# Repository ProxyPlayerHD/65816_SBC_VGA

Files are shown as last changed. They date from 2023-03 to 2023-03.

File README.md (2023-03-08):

# 65816 VGA Card
This is a simple VGA Expansion card designed for my 65816 SBC<br>
It uses an `ATF1508AS` CPLD for all the Logic, and 4x `IDT7005S` or `IDT7006S` Dual Port SRAM ICs for a total of either 32kB or 64kB of VRAM. (or something inbetween)

the Logic uploaded here is for 32kB of VRAM, 640x400 Monochrome (1 bit per pixel or "bpp") with an Interrupt every time a frame finished drawing.<br>
Though once i get my hands on some 16kB Chips i'll likely do a few more versions of the Logic and also upload them here.

# Folders
* "Downloaded Libs" contains the symbols and footprints for the KiCad Project
* "Logic" contains the... well Logic for the entire thing. i've included the original .dig file (requires [Digital](https://github.com/hneemann/Digital) to open), and already generated .v (Verilog) and .pof/.jed (program files in case you want to skip setting up Quartus to generate them yourself)
* "Gerbers" contains all required Gerbers to order yourself the PCB

# Misc

regards to the Logic:
the `CA13` line (CPU Address bit 13) is only required when dealing with 8kB DP-SRAM Chips,<br>
and the `VA13` (Video Address bit 13) line is only required when dealing with 16kB DP-SRAM Chips.<br>
also right now the decoding logic puts the VRAM on the CPU side at address `$FF8000`

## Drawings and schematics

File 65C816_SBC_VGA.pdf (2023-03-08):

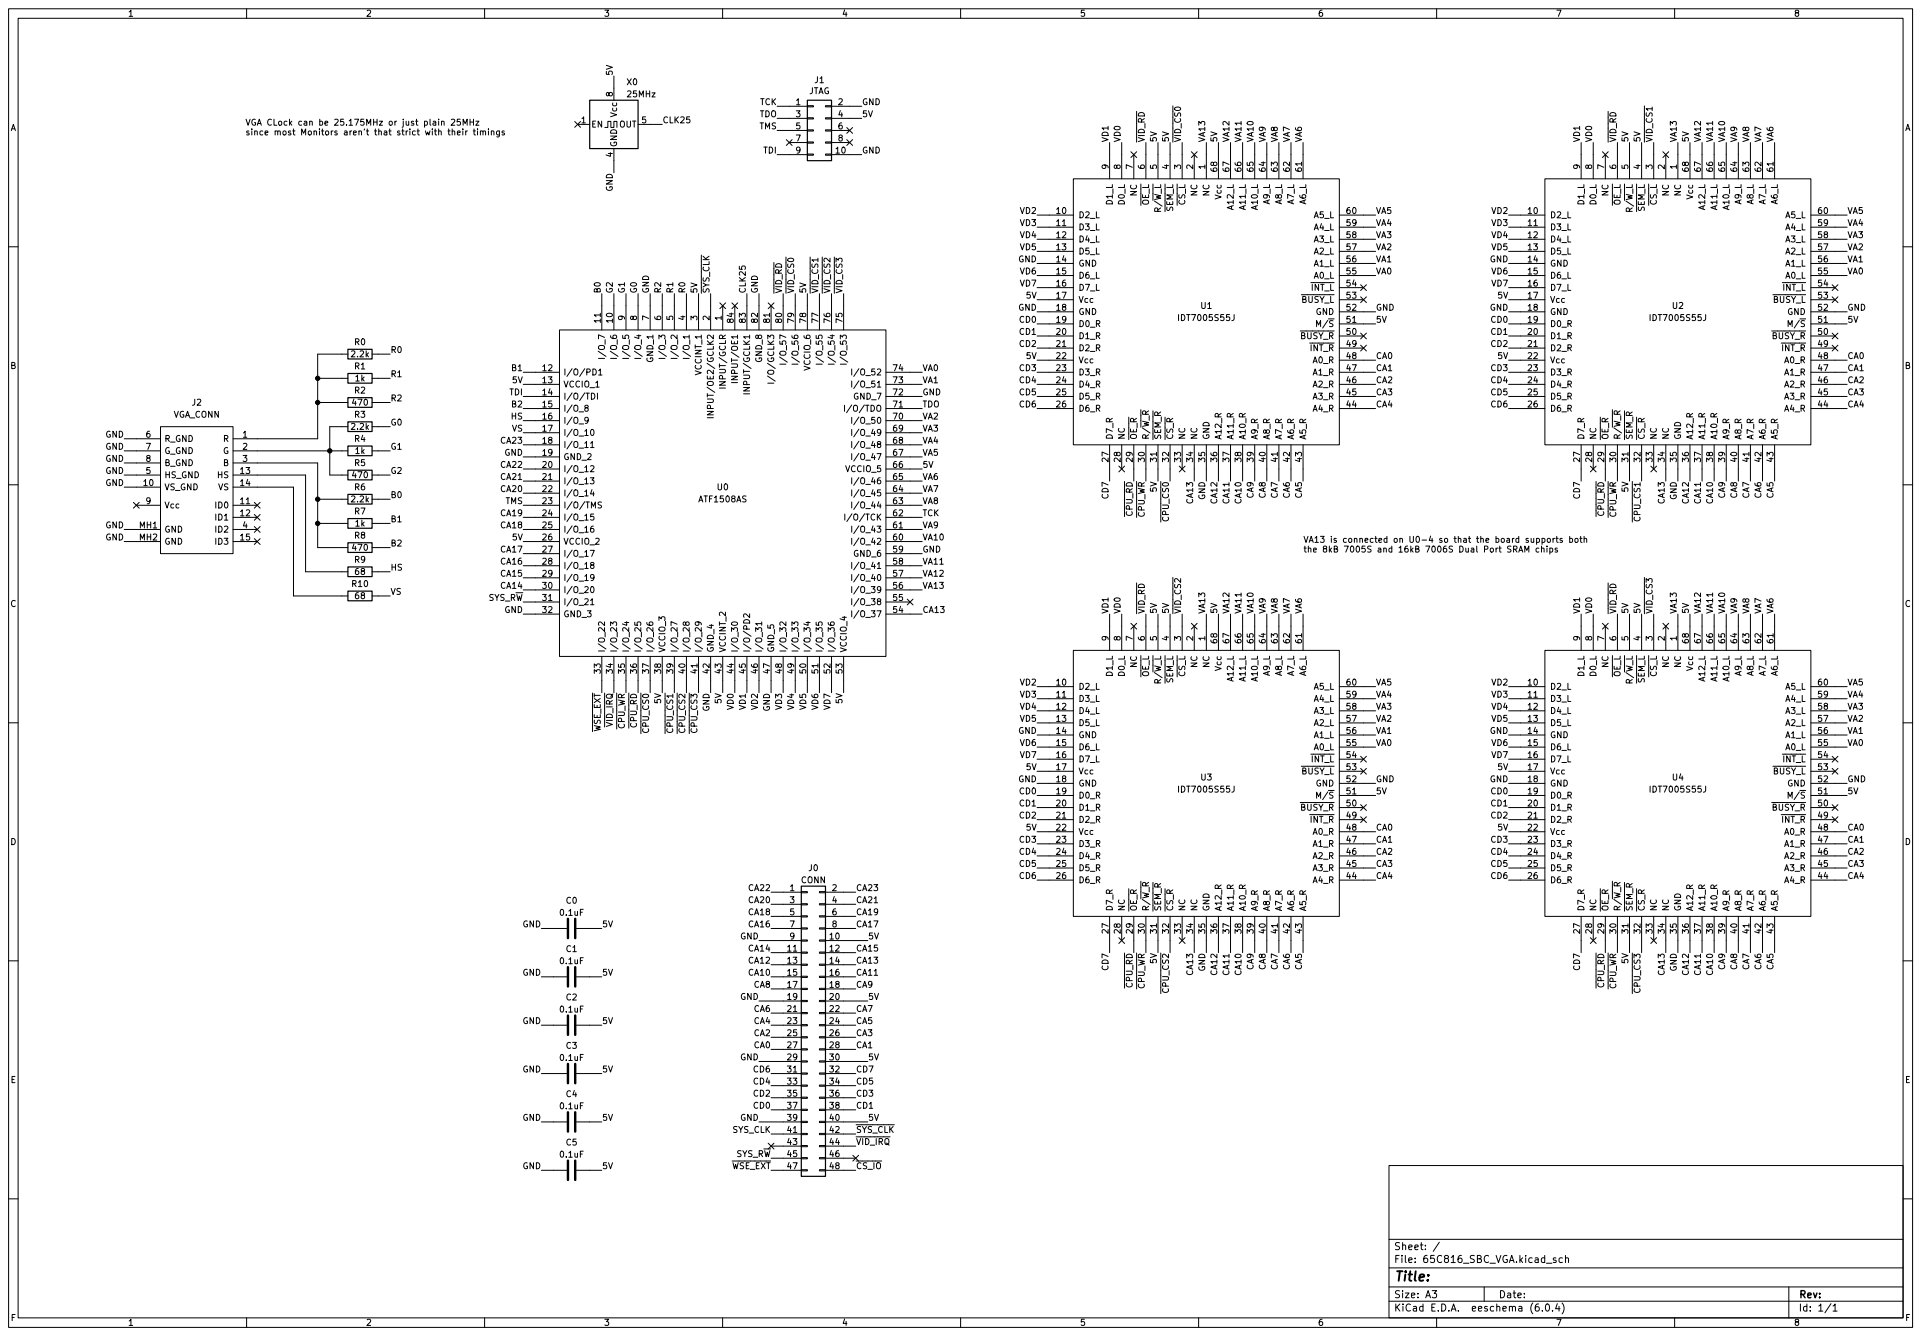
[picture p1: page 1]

VGA CLock can be 25.175MHz or just plain 25MHz
since most Monitors aren't that strict with their timings

2 D1_R 20 D2_R 21 Vcc 22 D3_R 23 D4_R 24 D5_R 25 D6_R 26 D7_R 27 NC 28 ~{OE_R} 29 ~{CS_L} 3 R/~{W_R} 30 ~{SEM_R} 31 ~{CS_R} 32 NC 33 NC 34 GND 35 A12_R 36 A11_R 37 A10_R 38 A9_R 39 ~{SEM_L} 4 A8_R 40 A7_R 41 A6_R 42 A5_R 43 A4_R 44 A3_R 45 A2_R 46 A1_R 47 A0_R 48 ~{INT_R} 49 R/~{W_L} 5 ~{BUSY_R} 50 M/~{S} 51 GND 52 ~{BUSY_L} 53 ~{INT_L} 54 A0_L 55 A1_L 56 A2_L 57 A3_L 58 A4_L 59 ~{OE_L} 6 A5_L 60 A6_L 61 A7_L 62 A8_L 63 A9_L 64 A10_L 65 A11_L 66 A12_L 67 Vcc 68 NC

1 D2_L 10 D3_L 11 D4_L 12 D5_L 13 GND 14 D6_L 15 D7_L 16 Vcc 17 GND 18 D0_R 19 NC

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

VA13 is connected on U0-4 so that the board supports both
the 8kB 7005S and 16kB 7006S Dual Port SRAM chips

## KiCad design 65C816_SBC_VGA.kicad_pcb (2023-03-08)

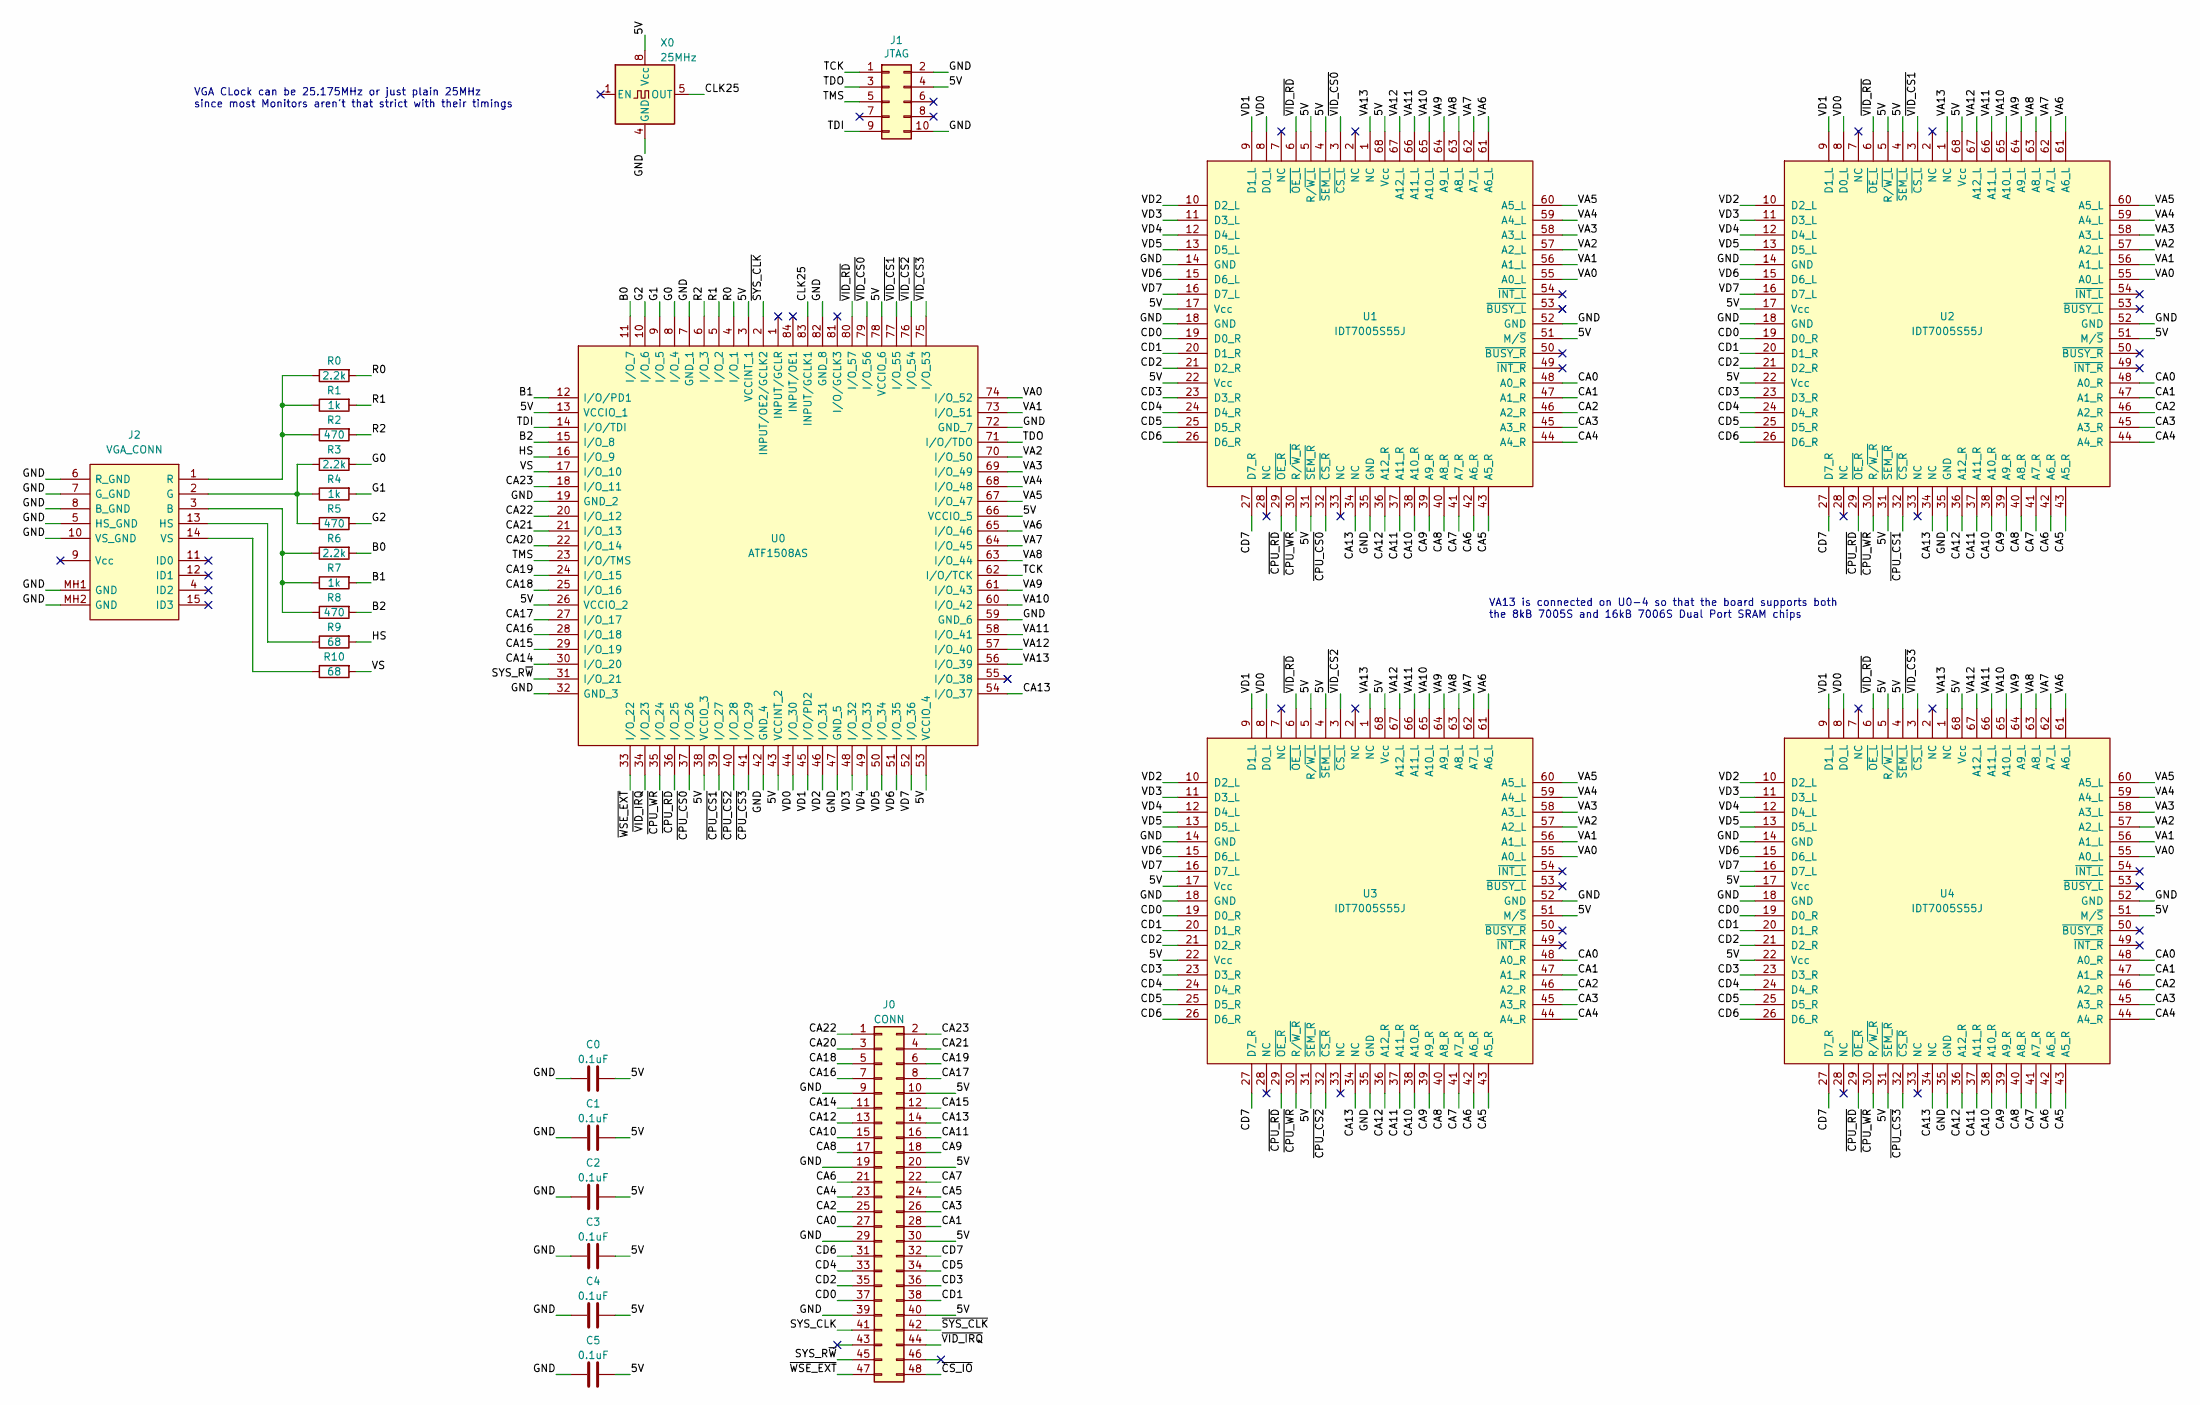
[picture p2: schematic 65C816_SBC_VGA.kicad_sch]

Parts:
C0, C1, C2, C3, C4, C5: 0.1uF; C_Disc_D4.3mm_W1.9mm_P5.00mm
J0: CONN; CARD_EDGE
J1: JTAG; PinHeader_2x05_P2.54mm_Vertical
J2: VGA_CONN; Mouser Part Number 156-3315-E
R0, R3, R6: 2.2k; R_Axial_DIN0207_L6.3mm_D2.5mm_P2.54mm_Vertical
R1, R4, R7: 1k; R_Axial_DIN0207_L6.3mm_D2.5mm_P2.54mm_Vertical
R2, R5, R8: 470; R_Axial_DIN0207_L6.3mm_D2.5mm_P2.54mm_Vertical
R9, R10: 68; R_Axial_DIN0207_L6.3mm_D2.5mm_P2.54mm_Vertical
U0: ATF1508AS; PLCC-84_THT-Socket
U1, U2, U3, U4: IDT7005S55J; PLCC-68_THT-Socket
X0: 25MHz; Oscillator_DIP-8

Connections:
/5V: C0.2, C1.2, C2.2, C3.2, C4.2, C5.2, J0.10, J0.20, J0.30, J0.40, J1.4, U0.3 (VCCINT_1), U0.13 (VCCIO_1), U0.26 (VCCIO_2), U0.38 (VCCIO_3), U0.43 (VCCINT_2), U0.53 (VCCIO_4), U0.66 (VCCIO_5), U0.78 (VCCIO_6), U1.4 (~SEM_L), U1.5 (R/~W_L), U1.17 (Vcc), U1.22 (Vcc), U1.31 (~SEM_R), U1.51 (M/~S), U1.68 (Vcc), U2.4 (~SEM_L), U2.5 (R/~W_L), U2.17 (Vcc), U2.22 (Vcc), U2.31 (~SEM_R), U2.51 (M/~S), U2.68 (Vcc), U3.4 (~SEM_L), U3.5 (R/~W_L), U3.17 (Vcc), U3.22 (Vcc), U3.31 (~SEM_R), U3.51 (M/~S), U3.68 (Vcc), U4.4 (~SEM_L), U4.5 (R/~W_L), U4.17 (Vcc), U4.22 (Vcc), U4.31 (~SEM_R), U4.51 (M/~S), U4.68 (Vcc), X0.8 (Vcc)
/B0: R6.2, U0.11 (I/O_7)
/B1: R7.2, U0.12 (I/O/PD1)
/B2: R8.2, U0.15 (I/O_8)
/CA0: J0.27, U1.48 (A0_R), U2.48 (A0_R), U3.48 (A0_R), U4.48 (A0_R)
/CA1: J0.28, U1.47 (A1_R), U2.47 (A1_R), U3.47 (A1_R), U4.47 (A1_R)
/CA2: J0.25, U1.46 (A2_R), U2.46 (A2_R), U3.46 (A2_R), U4.46 (A2_R)
/CA3: J0.26, U1.45 (A3_R), U2.45 (A3_R), U3.45 (A3_R), U4.45 (A3_R)
/CA4: J0.23, U1.44 (A4_R), U2.44 (A4_R), U3.44 (A4_R), U4.44 (A4_R)
/CA5: J0.24, U1.43 (A5_R), U2.43 (A5_R), U3.43 (A5_R), U4.43 (A5_R)
/CA6: J0.21, U1.42 (A6_R), U2.42 (A6_R), U3.42 (A6_R), U4.42 (A6_R)
/CA7: J0.22, U1.41 (A7_R), U2.41 (A7_R), U3.41 (A7_R), U4.41 (A7_R)
/CA8: J0.17, U1.40 (A8_R), U2.40 (A8_R), U3.40 (A8_R), U4.40 (A8_R)
/CA9: J0.18, U1.39 (A9_R), U2.39 (A9_R), U3.39 (A9_R), U4.39 (A9_R)
/CA10: J0.15, U1.38 (A10_R), U2.38 (A10_R), U3.38 (A10_R), U4.38 (A10_R)
/CA11: J0.16, U1.37 (A11_R), U2.37 (A11_R), U3.37 (A11_R), U4.37 (A11_R)
/CA12: J0.13, U1.36 (A12_R), U2.36 (A12_R), U3.36 (A12_R), U4.36 (A12_R)
/CA13: J0.14, U0.54 (I/O_37), U1.34 (NC), U2.34 (NC), U3.34 (NC), U4.34 (NC)
/CA14: J0.11, U0.30 (I/O_20)
/CA15: J0.12, U0.29 (I/O_19)
/CA16: J0.7, U0.28 (I/O_18)
/CA17: J0.8, U0.27 (I/O_17)
/CA18: J0.5, U0.25 (I/O_16)
/CA19: J0.6, U0.24 (I/O_15)
/CA20: J0.3, U0.22 (I/O_14)
/CA21: J0.4, U0.21 (I/O_13)
/CA22: J0.1, U0.20 (I/O_12)
/CA23: J0.2, U0.18 (I/O_11)
/CD0: J0.37, U1.19 (D0_R), U2.19 (D0_R), U3.19 (D0_R), U4.19 (D0_R)
/CD1: J0.38, U1.20 (D1_R), U2.20 (D1_R), U3.20 (D1_R), U4.20 (D1_R)
/CD2: J0.35, U1.21 (D2_R), U2.21 (D2_R), U3.21 (D2_R), U4.21 (D2_R)
/CD3: J0.36, U1.23 (D3_R), U2.23 (D3_R), U3.23 (D3_R), U4.23 (D3_R)
/CD4: J0.33, U1.24 (D4_R), U2.24 (D4_R), U3.24 (D4_R), U4.24 (D4_R)
/CD5: J0.34, U1.25 (D5_R), U2.25 (D5_R), U3.25 (D5_R), U4.25 (D5_R)
/CD6: J0.31, U1.26 (D6_R), U2.26 (D6_R), U3.26 (D6_R), U4.26 (D6_R)
/CD7: J0.32, U1.27 (D7_R), U2.27 (D7_R), U3.27 (D7_R), U4.27 (D7_R)
/CLK25: U0.83 (INPUT/GCLK1), X0.5 (OUT)
/G0: R3.2, U0.8 (I/O_4)
/G1: R4.2, U0.9 (I/O_5)
/G2: R5.2, U0.10 (I/O_6)
/GND: C0.1, C1.1, C2.1, C3.1, C4.1, C5.1, J0.9, J0.19, J0.29, J0.39, J1.2, J1.10, J2.5 (HS_GND), J2.6 (R_GND), J2.7 (G_GND), J2.8 (B_GND), J2.10 (VS_GND), J2.MH1 (GND), J2.MH2 (GND), U0.7 (GND_1), U0.19 (GND_2), U0.32 (GND_3), U0.42 (GND_4), U0.47 (GND_5), U0.59 (GND_6), U0.72 (GND_7), U0.82 (GND_8), U1.14 (GND), U1.18 (GND), U1.35 (GND), U1.52 (GND), U2.14 (GND), U2.18 (GND), U2.35 (GND), U2.52 (GND), U3.14 (GND), U3.18 (GND), U3.35 (GND), U3.52 (GND), U4.14 (GND), U4.18 (GND), U4.35 (GND), U4.52 (GND), X0.4 (GND)
/HS: R9.2, U0.16 (I/O_9)
/R0: R0.2, U0.4 (I/O_1)
/R1: R1.2, U0.5 (I/O_2)
/R2: R2.2, U0.6 (I/O_3)
/SYS_CLK: J0.41
/SYS_R~W: J0.45, U0.31 (I/O_21)
/TCK: J1.1, U0.62 (I/O/TCK)
/TDI: J1.9, U0.14 (I/O/TDI)
/TDO: J1.3, U0.71 (I/O/TDO)
/TMS: J1.5, U0.23 (I/O/TMS)
/VA0: U0.74 (I/O_52), U1.55 (A0_L), U2.55 (A0_L), U3.55 (A0_L), U4.55 (A0_L)
/VA1: U0.73 (I/O_51), U1.56 (A1_L), U2.56 (A1_L), U3.56 (A1_L), U4.56 (A1_L)
/VA2: U0.70 (I/O_50), U1.57 (A2_L), U2.57 (A2_L), U3.57 (A2_L), U4.57 (A2_L)
/VA3: U0.69 (I/O_49), U1.58 (A3_L), U2.58 (A3_L), U3.58 (A3_L), U4.58 (A3_L)
/VA4: U0.68 (I/O_48), U1.59 (A4_L), U2.59 (A4_L), U3.59 (A4_L), U4.59 (A4_L)
/VA5: U0.67 (I/O_47), U1.60 (A5_L), U2.60 (A5_L), U3.60 (A5_L), U4.60 (A5_L)
/VA6: U0.65 (I/O_46), U1.61 (A6_L), U2.61 (A6_L), U3.61 (A6_L), U4.61 (A6_L)
/VA7: U0.64 (I/O_45), U1.62 (A7_L), U2.62 (A7_L), U3.62 (A7_L), U4.62 (A7_L)
/VA8: U0.63 (I/O_44), U1.63 (A8_L), U2.63 (A8_L), U3.63 (A8_L), U4.63 (A8_L)
/VA9: U0.61 (I/O_43), U1.64 (A9_L), U2.64 (A9_L), U3.64 (A9_L), U4.64 (A9_L)
/VA10: U0.60 (I/O_42), U1.65 (A10_L), U2.65 (A10_L), U3.65 (A10_L), U4.65 (A10_L)
/VA11: U0.58 (I/O_41), U1.66 (A11_L), U2.66 (A11_L), U3.66 (A11_L), U4.66 (A11_L)
/VA12: U0.57 (I/O_40), U1.67 (A12_L), U2.67 (A12_L), U3.67 (A12_L), U4.67 (A12_L)
/VA13: U0.56 (I/O_39), U1.1 (NC), U2.1 (NC), U3.1 (NC), U4.1 (NC)
/VD0: U0.44 (I/O_30), U1.8 (D0_L), U2.8 (D0_L), U3.8 (D0_L), U4.8 (D0_L)
/VD1: U0.45 (I/O/PD2), U1.9 (D1_L), U2.9 (D1_L), U3.9 (D1_L), U4.9 (D1_L)
/VD2: U0.46 (I/O_31), U1.10 (D2_L), U2.10 (D2_L), U3.10 (D2_L), U4.10 (D2_L)
/VD3: U0.48 (I/O_32), U1.11 (D3_L), U2.11 (D3_L), U3.11 (D3_L), U4.11 (D3_L)
/VD4: U0.49 (I/O_33), U1.12 (D4_L), U2.12 (D4_L), U3.12 (D4_L), U4.12 (D4_L)
/VD5: U0.50 (I/O_34), U1.13 (D5_L), U2.13 (D5_L), U3.13 (D5_L), U4.13 (D5_L)
/VD6: U0.51 (I/O_35), U1.15 (D6_L), U2.15 (D6_L), U3.15 (D6_L), U4.15 (D6_L)
/VD7: U0.52 (I/O_36), U1.16 (D7_L), U2.16 (D7_L), U3.16 (D7_L), U4.16 (D7_L)
/VS: R10.2, U0.17 (I/O_10)
/~CPU_CS0: U0.37 (I/O_26), U1.32 (~CS_R)
/~CPU_CS1: U0.39 (I/O_27), U2.32 (~CS_R)
/~CPU_CS2: U0.40 (I/O_28), U3.32 (~CS_R)
/~CPU_CS3: U0.41 (I/O_29), U4.32 (~CS_R)
/~CPU_RD: U0.36 (I/O_25), U1.29 (~OE_R), U2.29 (~OE_R), U3.29 (~OE_R), U4.29 (~OE_R)
/~CPU_WR: U0.35 (I/O_24), U1.30 (R/~W_R), U2.30 (R/~W_R), U3.30 (R/~W_R), U4.30 (R/~W_R)
/~CS_IO: J0.48
/~SYS_CLK: J0.42, U0.2 (INPUT/OE2/GCLK2)
/~VID_CS0: U0.79 (I/O_56), U1.3 (~CS_L)
/~VID_CS1: U0.77 (I/O_55), U2.3 (~CS_L)
/~VID_CS2: U0.76 (I/O_54), U3.3 (~CS_L)
/~VID_CS3: U0.75 (I/O_53), U4.3 (~CS_L)
/~VID_IRQ: J0.44, U0.34 (I/O_23)
/~VID_RD: U0.80 (I/O_57), U1.6 (~OE_L), U2.6 (~OE_L), U3.6 (~OE_L), U4.6 (~OE_L)
/~WSE_EXT: J0.47, U0.33 (I/O_22)
unnamed: J2.1 (R), R0.1, R1.1, R2.1
unnamed: J2.2 (G), R3.1, R4.1, R5.1
unnamed: J2.3 (B), R6.1, R7.1, R8.1
unnamed: J2.13 (HS), R9.1
unnamed: J2.14 (VS), R10.1

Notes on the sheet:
VGA CLock can be 25.175MHz or just plain 25MHz since most Monitors aren't that strict with their timings
VA13 is connected on U0-4 so that the board supports both the 8kB 7005S and 16kB 7006S Dual Port SRAM chips

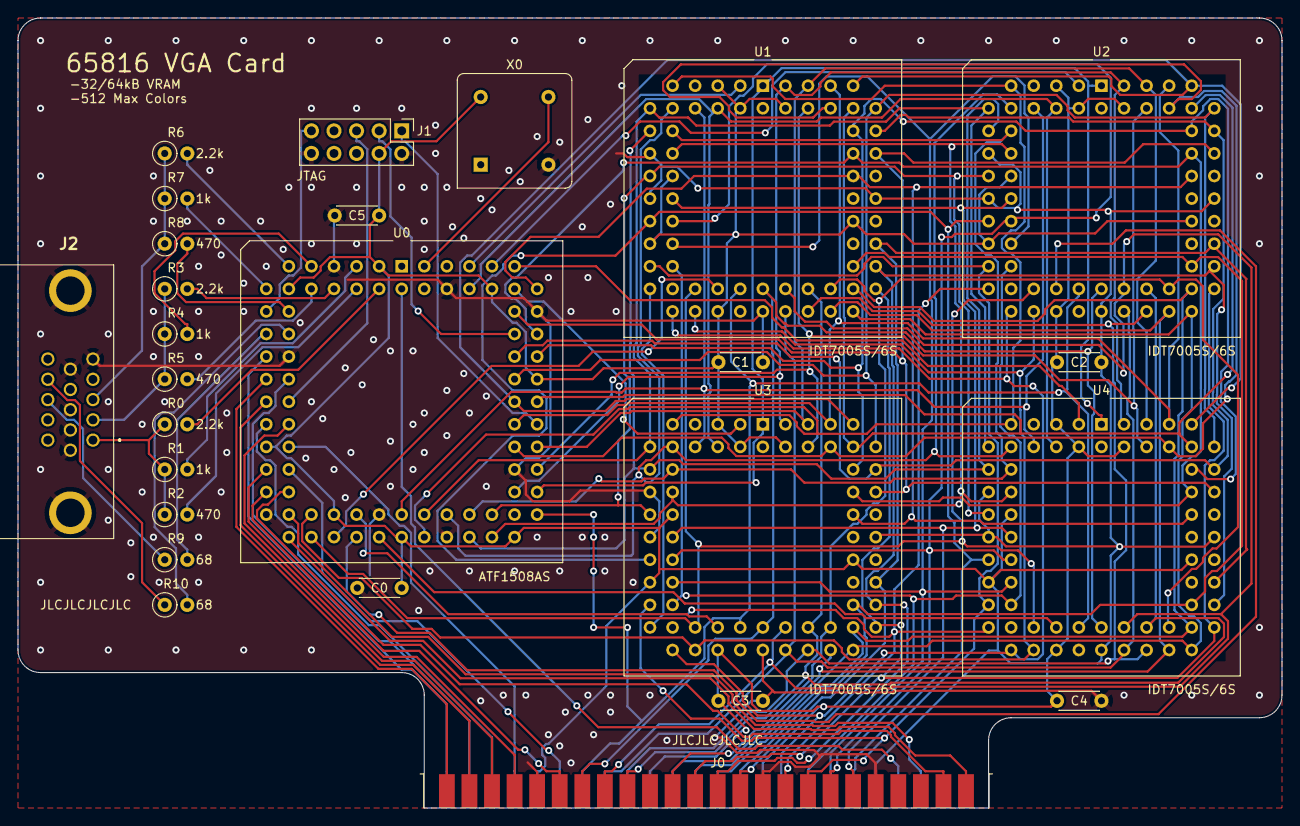
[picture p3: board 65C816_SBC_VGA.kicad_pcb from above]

Board: 2 copper layers, 142.2 x 88.9 mm, 26 parts (0 on the bottom side), 92 nets.
